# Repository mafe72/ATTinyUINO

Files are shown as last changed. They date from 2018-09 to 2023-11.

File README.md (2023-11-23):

# Official ATTinyUINO DIY Board Repository



For more details on design, assembly and programming, visit the documentation: [ATTinyUINO-docs](https://github.com/mafe72/ATTinyUINO/tree/master/ATTinyUINO-docs)

License
-------
<div align="center"><br /></div>

This project is open hardware licensed under the Attribution-ShareAlike 4.0 (CC BY-SA 4.0) license. The full legal text of the license may be found in the LICENSE.md file in this repository. For more information about this license, please visit 
the Creative Commons Foundation (https://creativecommons.org/licenses/by-sa/4.0/).

Characteristics of ATTinyUINO DIY
-------

- Single Face Plate - To make it easier to make homemade
- Components in TH - For manual mounting (SMD is also available)
- ATtiny85-20PU Micro-controller - Arduino Compatibility
- 5 pin I / O - All micro-controller pins will be available
- POWER LED - LED for power indication
- General purpose LED connected to I/O pin 1

----------
ATTinyUINO TH Front Side:
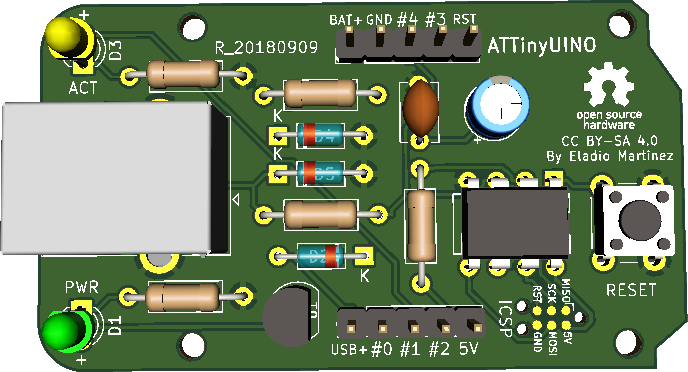
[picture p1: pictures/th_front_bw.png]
ATTinyUINO TH Front Side

----------
ATTinyUINO SMD Front Side:
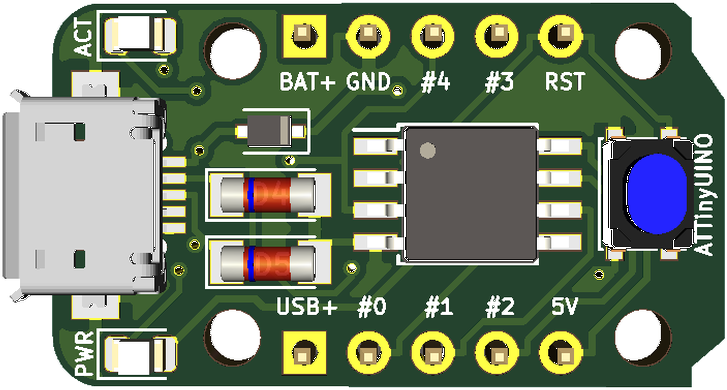
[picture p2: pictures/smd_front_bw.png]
ATTinyUINO SMD Front Side

----------
ATTinyUINO SMD Back Side:
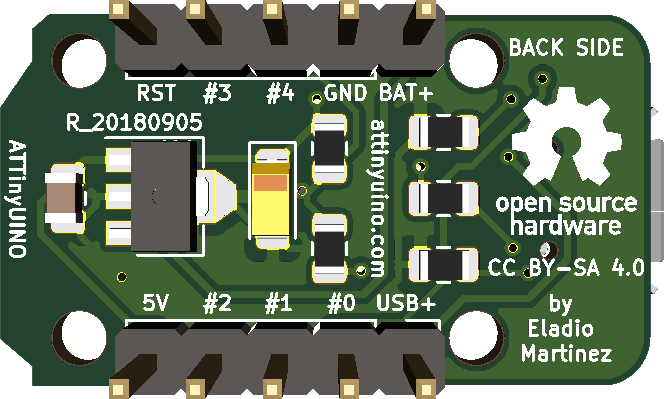
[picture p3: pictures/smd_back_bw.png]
ATTinyUINO SMD Back Side

----------

Project
-------

The PCB design was originally developed in Kicad.

# Contribution

## Suggestions and Bugs in Hardware

You should report bugs or suggestions via [Issues area](https://github.com/mafe72/ATTinyUINO/issues) here in github.

Make sure you meet the following criteria when creating / submitting your issue:

- Use a clear and descriptive title to identify the problem / suggestion.
- Describe the exact steps to reproduce the problem in as much detail as possible.
- Mention where this problem was found / what your suggestion will affect.

## Contribution to hardware improvements

Community contributions are always welcome!

This section is intended to help anyone interested in contributing to this repository.
Before you contribute, first get approval from the repository and community maintainers by raising a problem from GitHub using the guidelines mentioned in the suggestions section.
 
Once you get approved, you will need to do the following steps (these instructions assume that you are a GitHub user).

- 1: Fork this repository.
- 2: Make changes, commit and push to the fork.
- 3: Submit your Pull Request.

## If you have any questions please contact me

info@attinyuino.com

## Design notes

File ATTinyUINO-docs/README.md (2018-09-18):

# ATTinyUINO Project Documentation

Here you will find all the content for assembly and use of the Board, as well as some examples of projects. If you want to collaborate, or see any errors, feel free to create an Issue or contact the project administrators.

The documentation is divided into topics, where each topic is a directory with the specific content. If you have trouble finding the information, please leave a feedback.

If you want to get in touch with the project administrators, please send an email to: info@attinyuino.com

1. **ATTinyUINO**
	* List of materials (BOM)
	* Identifying components
	* Assembling the TH board version
	* Assembling the SMD board version
	* [Pinout](https://github.com/mafe72/ATTinyUINO/tree/master/ATTinyUINO-docs/01-ATTinyUINO/Pinout)
	* Burning the bootloader
  	* Drivers
	* Arduino IDE Configuration
	* Upload the Sketch

2. **Arduino Functions**

	- Digital Inputs and Outputs
	- Analog Inputs
	- PWM
	- I2C

3. **Project Examples**

- LED Blink
- LED brightness control
- Key Reading
- Power key
- Light sensor with LDR
- Traffic light

4. **Troubleshooting**

5. **FAQ**

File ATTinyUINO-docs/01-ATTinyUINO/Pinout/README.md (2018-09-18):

# ATTinyUINO Pinout

### ATTinyUINO TH Pinout

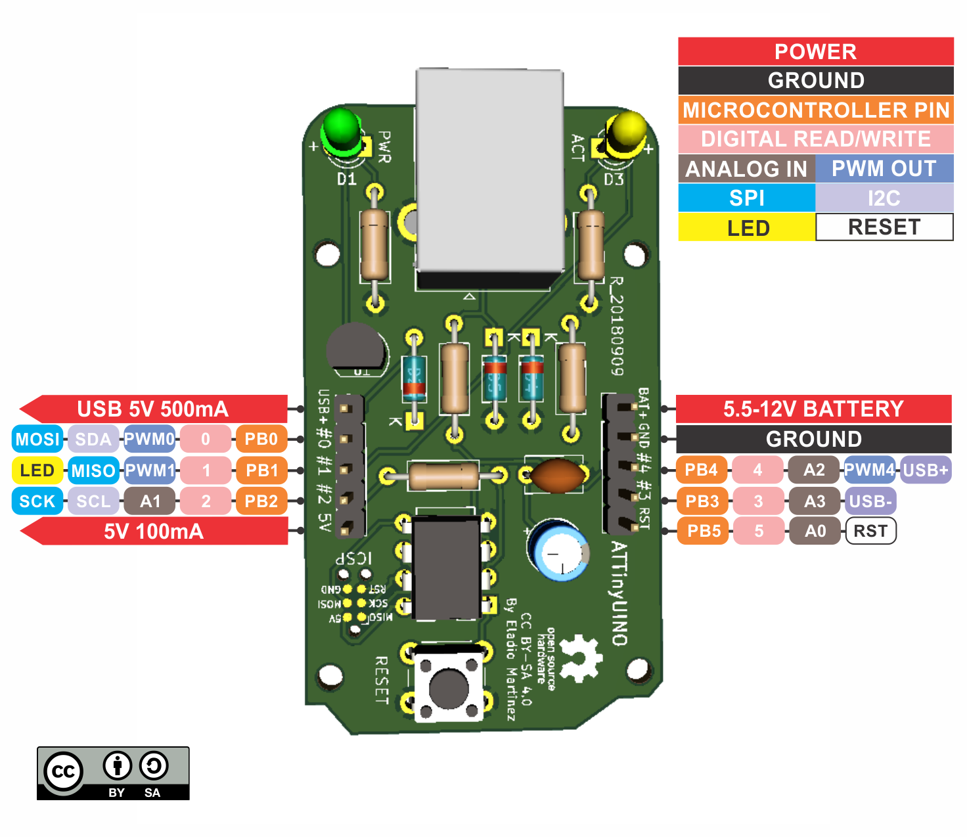
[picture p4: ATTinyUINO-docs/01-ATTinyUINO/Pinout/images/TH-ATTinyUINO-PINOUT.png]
ATTinyUINO TH Pinout


### ATTinyUINO SMD Pinout

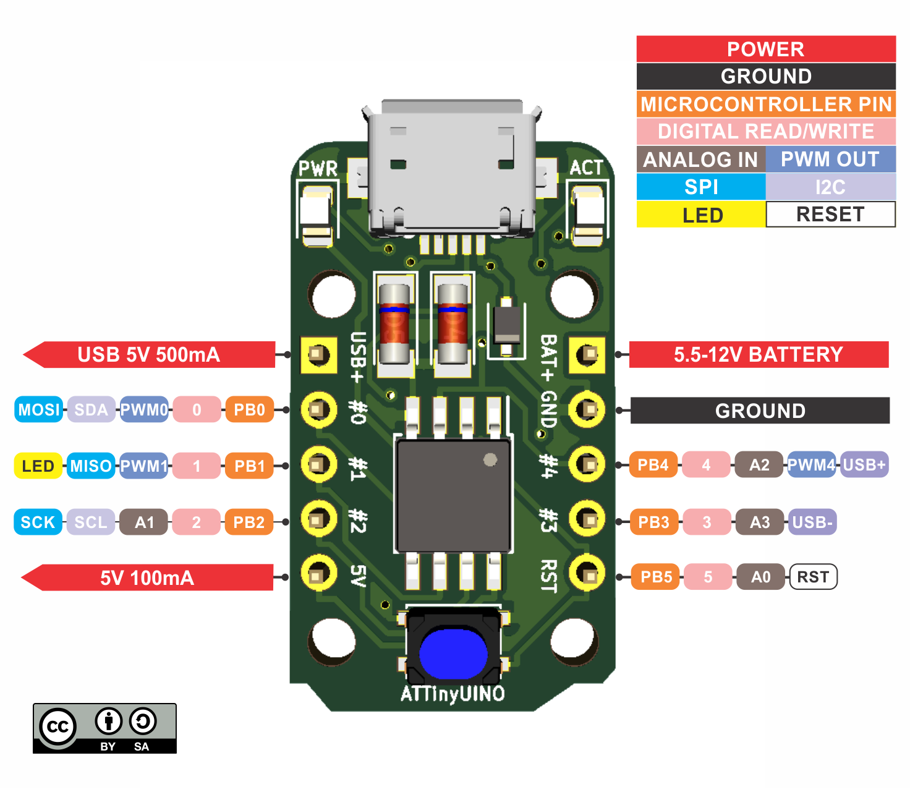
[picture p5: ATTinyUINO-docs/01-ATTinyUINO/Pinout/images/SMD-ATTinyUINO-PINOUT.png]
ATTinyUINO SMD Pinout


*The output pinout of the two versions are the same.

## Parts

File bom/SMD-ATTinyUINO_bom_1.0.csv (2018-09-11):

Component | Description | References | Value | Quantity Per PCB | MPN | Datasheet
1 | 0.1 µF 50V Ceramic Capacitor X7R 0805 (2012 Metric) 0.079" L x 0.049" W (2.00mm x 1.25mm) | C2 | 0.1uF | 1 | CC0805KRX7R9BB104 | http://www.yageo.com/documents/recent/UPY-GPHC_X7R_6.3V-to-50V_18.pdf
2 | 10 µF Molded Tantalum Capacitors 10V 1206 (3216 Metric) 3 Ohm | C1 | 10uF | 1 | TAJA106K010RNJ | http://datasheets.avx.com/TAJ.pdf
3 | Diode Standard 75V 150mA Surface Mount SOD-323F | D2 | 1N4148WS | 1 | 1N4148WS | https://www.fairchildsemi.com/datasheets/1N/1N4148WS.pdf
4 | Green 571nm LED Indication - Discrete 2V 0805 (2012 Metric) | D1 | LED_GRN | 1 | LTST-C171KGKT | http://optoelectronics.liteon.com/upload/download/DS22-2000-118/LTST-C171KGKT.pdf
5 | Yellow-Green 573nm LED Indication - Discrete 2V 0805 (2012 Metric) | D3 | LED_YELL | 1 | 17-215SYGC/S530-E2/TR8 | https://media.digikey.com/pdf/Data%20Sheets/Everlight%20PDFs/17-215SYGC-S530-XX-TR8.pdf
6 | Zener Diode 3.6V 500mW ±5% Surface Mount SOD-80 MiniMELF | D4 D5 | TZMC3V6 | 2 | TZMC3V6-GS08 | http://www.vishay.com/docs/84122/tzm.pdf
7 | Connector Header Through Hole 5 position 0.100" (2.54mm) | J1 J2 | Conn_01x05 | 2 | 61300511121 | https://katalog.we-online.de/em/datasheet/6130xx11121.pdf
8 | USB - micro AB USB 2.0 Receptacle Connector 5 Position Surface Mount, Right Angle | J3 | USB_OTG | 1 | 10104111-0001LF | https://cdn.amphenol-icc.com/media/wysiwyg/files/drawing/10104111.pdf
9 | 1 kOhms ±5% 0.125W, 1/8W Chip Resistor 0805 (2012 Metric) Moisture Resistant Thick Film | R1 R2 | 1K | 2 | RC0805JR-071KL | http://www.yageo.com/documents/recent/PYu-RC_Group_51_RoHS_L_9.pdf
10 | 1.5 kOhms ±1% 0.125W, 1/8W Chip Resistor 0805 (2012 Metric) Moisture Resistant Thick Film | R4 | 1K5 | 1 | RC0805FR-071K5L | http://www.yageo.com/documents/recent/PYu-RC_Group_51_RoHS_L_9.pdf
11 | 68 Ohms ±5% 0.125W, 1/8W Chip Resistor 0805 (2012 Metric) Moisture Resistant Thick Film | R3 R5 | 68R | 2 | RC0805JR-0768RL | http://www.yageo.com/documents/recent/PYu-RC_Group_51_RoHS_L_9.pdf
12 | Tactile Switch SPST-NO Top Actuated Surface Mount | SW1 | RESET | 1 | TL3365AF180QG | https://www.e-switch.com/system/asset/product_line/data_sheet/218/TL3365.pdf
13 | AVR AVR® ATtiny Microcontroller IC 8-Bit 20MHz 8KB (4K x 16) FLASH 8-SOIC | U2 | ATtiny85-20SU | 1 | ATTINY85-20SUR | http://ww1.microchip.com/downloads/en/DeviceDoc/atmel-2586-avr-8-bit-microcontroller-attiny25-attiny45-attiny85_datasheet.pdf
14 | Linear Voltage Regulator IC Positive Fixed 1 Output 5V 100mA SOT-89-3 | U1 | L78L05_SOT89 | 1 | L78L05ABUTR | http://www.st.com/content/ccc/resource/technical/document/datasheet/15/55/e5/aa/23/5b/43/fd/CD00000446.pdf/files/CD00000446.pdf/jcr:content/translations/en.CD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

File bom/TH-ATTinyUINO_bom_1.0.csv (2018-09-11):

Component | Description | References | Value | Quantity Per PCB | MPN | Datasheet
1 | CAP CER 0.1UF 50V X7R RADIAL | C2 | 0.1uF | 1 | C322C104K5R5TA | https://content.kemet.com/datasheets/KEM_C1050_GOLDMAX_X7R.pdf
2 | 10 µF 35V Aluminum Electrolytic Capacitors Radial, Can 2000 Hrs @ 85°C | C1 | 10uF | 1 | 10 uF x 35 V | https://media.digikey.com/pdf/Data%20Sheets/Panasonic%20Electronic%20Components/ECA-xxM%20Series,TypeA.pdf
3 | Diode Standard 75V 150mA Through Hole DO-35 | D2 | 1N4148 | 1 | 1N4148 TR | https://www.fairchildsemi.com/datasheets/1N/1N4148WS.pdf
4 | Zener Diode 3.6V 500mW ±5% Through Hole DO-35 | D4 D5 | BZX55C3V6 | 2 | BZX55C3V6-TAP | http://www.vishay.com/docs/85604/bzx55-se.pdf
5 | Green 569nm LED Indication - Discrete 2.4V Radial | D1 | LED_GRN | 1 | TLHG4400-AS12 | http://www.vishay.com/docs/83006/tlhg440.pdf
6 | Yellow 588nm LED Indication - Discrete 2.4V Radial | D3 | LED_YELL | 1 | TLHY4400-AS12Z | http://www.vishay.com/docs/83006/tlhg440.pdf
7 | Connector Header Through Hole 5 position 0.100" (2.54mm) | J1 J2 | Conn_01x05 | 2 | 61300511121 | https://katalog.we-online.de/em/datasheet/6130xx11121.pdf
8 | USB - B USB 2.0 Receptacle Connector 4 Position Through Hole, Right Angle | J3 | USB_B | 1 | 61400416121 | https://katalog.we-online.de/em/datasheet/61400416121.pdf
9 | TC2030-IDC-NL 6-Pin No-Legs Tag-Connect Plug-of-NailsTM Cable with Ribbon Connector | P1 | TC2030-IDC | 1 | TC2030-IDC | http://www.tag-connect.com/Materials/TC2030-IDC-NL.pdf
10 | 1 kOhms ±5% 0.25W, 1/4W Through Hole Resistor Axial Carbon Film | R1 R2 | 1K | 2 | CFR-25JB-52-1K | http://www.yageo.com/NewPortal/yageodocoutput?fileName=/pdf/throughhole/Yageo_LR_CFR_2013.pdf
11 | 1.5 kOhms ±5% 0.25W, 1/4W Through Hole Resistor Axial Carbon Film | R4 | 1K5 | 1 | CFR-25JB-52-1K5 | http://www.yageo.com/NewPortal/yageodocoutput?fileName=/pdf/throughhole/Yageo_LR_CFR_2013.pdf
12 | 68 Ohms ±5% 0.25W, 1/4W Through Hole Resistor Axial Carbon Film | R3 R5 | 68R | 2 | CFR-25JB-52-68R | http://www.yageo.com/NewPortal/yageodocoutput?fileName=/pdf/throughhole/Yageo_LR_CFR_2013.pdf
13 | Tactile Switch SPST-NO Top Actuated Through Hole | SW1 | RESET | 1 | TL1105AF160Q | https://www.e-switch.com/system/asset/product_line/data_sheet/144/TL1105.pdf
14 | AVR AVR® ATtiny Microcontroller IC 8-Bit 20MHz 8KB (4K x 16) FLASH 8-PDIP | U2 | ATTINY85-20PU | 1 | ATTINY85-20PU | http://ww1.microchip.com/downloads/en/DeviceDoc/atmel-2586-avr-8-bit-microcontroller-attiny25-attiny45-attiny85_datasheet.pdf
15 | Linear Voltage Regulator IC Positive Fixed 1 Output 5V 100mA TO-92-3 | U1 | L78L05_SOT89 | 1 | L78L05ABZ-TR | https://www.st.com/content/ccc/resource/technical/document/datasheet/15/55/e5/aa/23/5b/43/fd/CD00000446.pdf/files/CD00000446.pdf/jcr:content/translations/en.C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

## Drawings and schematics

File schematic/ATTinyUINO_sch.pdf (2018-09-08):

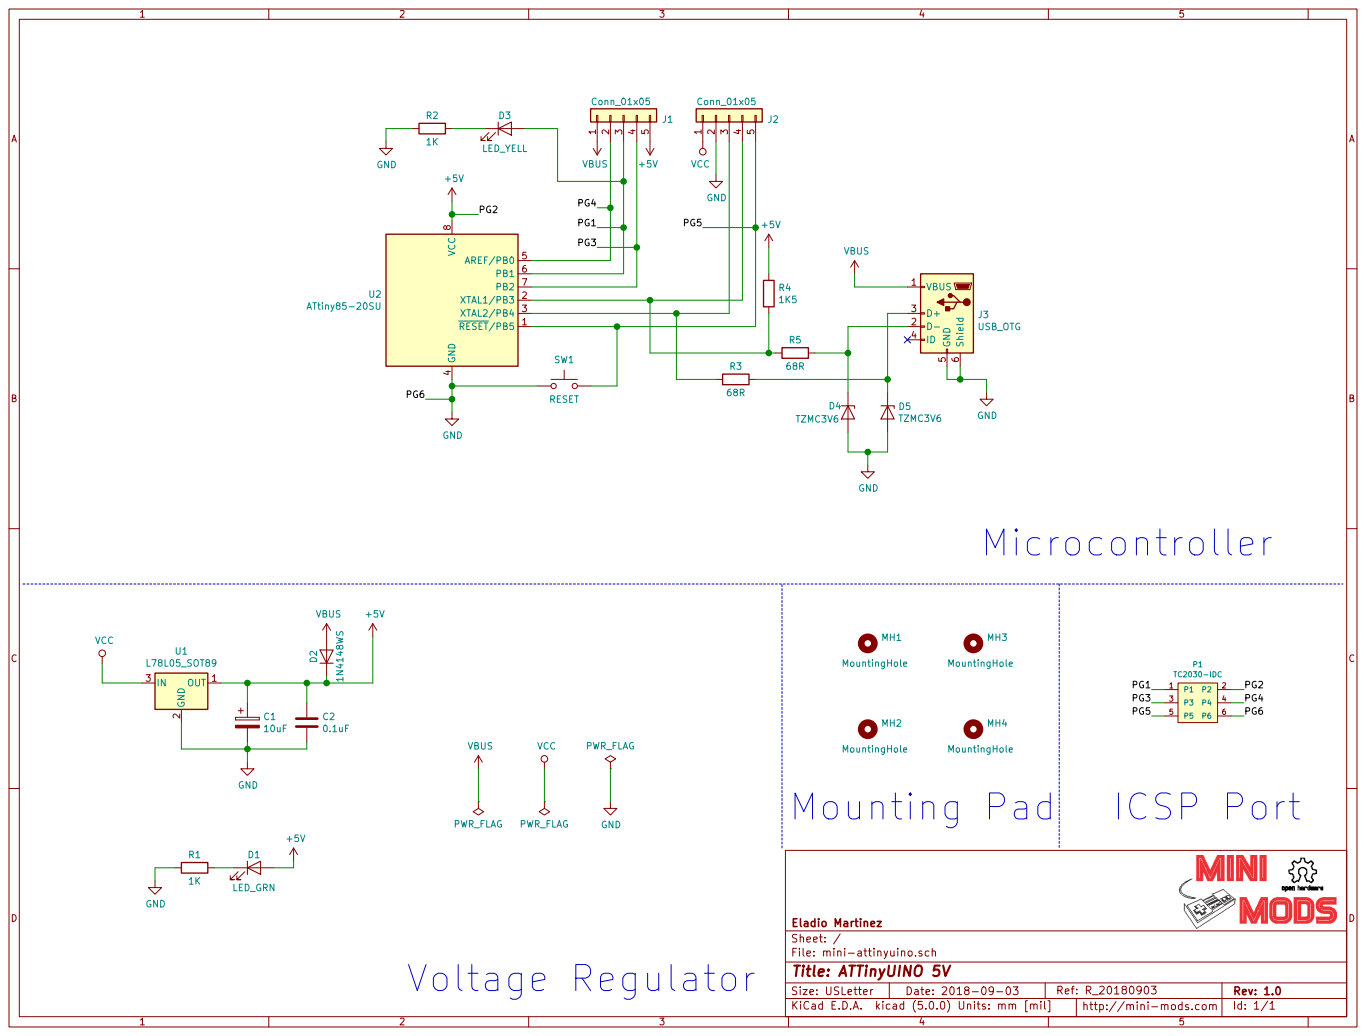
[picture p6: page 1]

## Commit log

2018-09-11 Update BOM
    [SMD-ATTinyUINO_bom_1.0.csv, TH-ATTinyUINO_bom_1.0.csv]
2018-09-12 Update gerber naming
    [mini-attinyuino-B.Cu.gbr, mini-attinyuino-B.Mask.gbr, mini-attinyuino-B.SilkS.gbr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]
2018-09-14 Add Interactive bom
